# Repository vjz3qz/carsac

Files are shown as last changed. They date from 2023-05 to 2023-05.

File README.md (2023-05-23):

# CARS Access Control
Access control solution for the Charlottesville-Albemarle Rescue Squad. The CARS Access Control Software is an RFID badge scanning system for streamlined and secure access control. It offers real-time monitoring and customizable access management for enhanced security.

## License
Copyright 2021, 2022 by John Kothmann, Tom Baker, and Varun Pasupuleti

This file is part of CARSAC.

CARSAC is free software: you can redistribute it and/or modify it under the terms of the GNU General Public License as published by the Free Software Foundation, either version 3 of the License, or (at your option) any later version.

CARSAC is distributed in the hope that it will be useful, but WITHOUT ANY WARRANTY; without even the implied warranty of MERCHANTABILITY or FITNESS FOR A PARTICULAR PURPOSE. See the GNU General Public License for more details.

You should have received a copy of the GNU General Public License along with CARSAC. If not, see <https://www.gnu.org/licenses/>.

## Hardware and setup

Install a strike in the door. Use a fail-secure strike for secure facilities like a telecom closet and fail-open for doors essential for egress and rescue workers like main entrances. In the event of a power outage and depletion of the backup battery, does the door need to be locked or unlocked? Ideally, install the diode to prevent high-voltage spikes when power is disconnected but the strike coil magnetic field transiently remains.

Print a case and attach Pi 0W, Adafruit Trinket/Feather, and wiring board to the case. Solder headers to the Pi 0W and wiring board if desired for easier troubleshooting. Otherwise, solder wires between elements as indicated on the wiring board.

Connect the power supply to the wiring board per the labels on the wiring board. Use Normally Closed (NC) for fail-open and Normally Open (NO) for fail-secure strikes.

## Configuration

Install Raspbian (32-bit, headless/the lightest image possible).

Update the hostname and enable SSH with `sudo raspi-config` (general and interfacing options).

Delete the default pi user (`sudo userdel pi`)

Add desired users and their SSH keys and add them to the sudoers group (`sudo useradd -m -G sudo ansible` then `ssh-copy-id -i ~/.ssh/id_ed25519.pub ansible@A.B.C.D`)

Clone git repo into /etc/carsac (may work best with scp from host after `sudo mkdir /etc/carsac`)

Edit door-specific config information in `/etc/carsac/config.ini` (door_id)

Set up CARSAC service with `sudo mv /etc/carsac/carsac.service /etc/systemd/system/carsac.service`, `sudo systemctl daemon-reload`, `sudo systemctl enable carsac`, `sudo systemctl start carsac`

Test for functionality

Set DHCP reservation on the router and add the new machine IP to /etc/ansible/hosts on the ansible master node. Login from the master to the client via SSH and perform fingerprint verification.

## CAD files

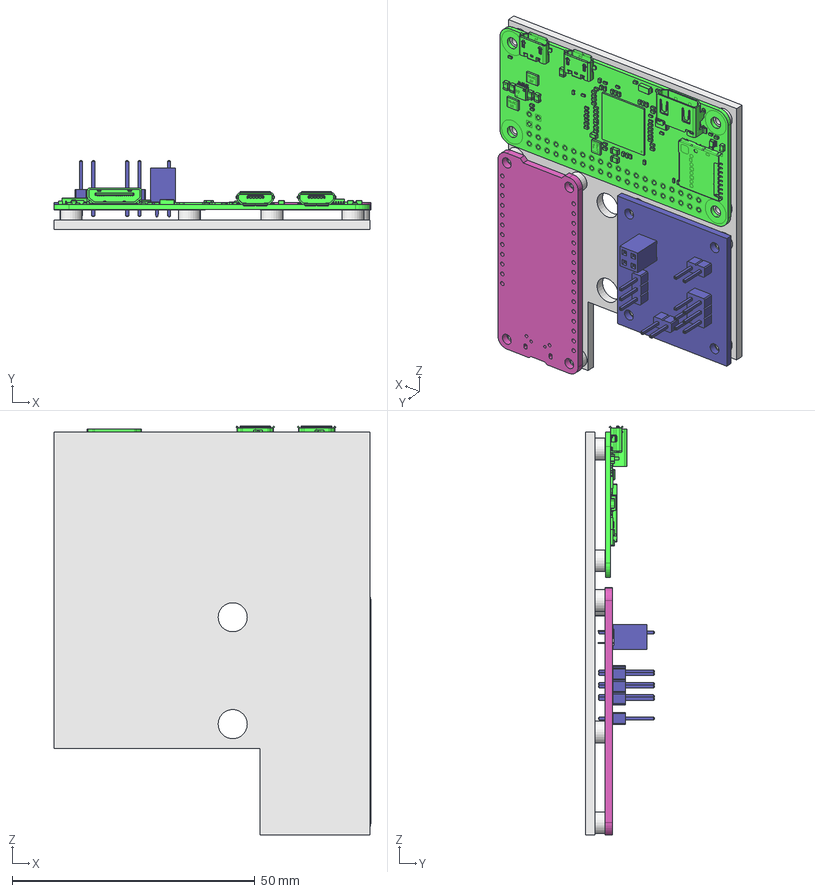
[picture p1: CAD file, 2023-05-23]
hardware/FlatCaseFeather.FCStd
65.2 x 14.2 x 84.2 mm
RapberryPiZero
ACWB
Feather
Merged

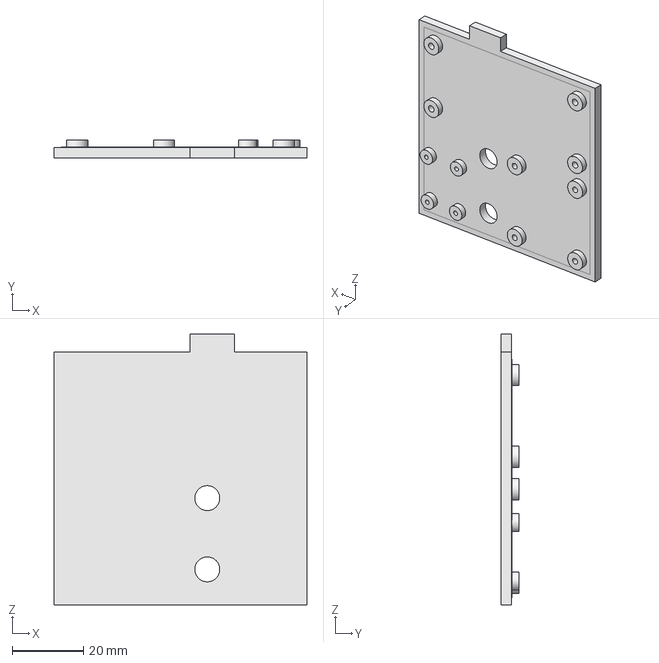
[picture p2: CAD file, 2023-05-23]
hardware/FlatCaseTrinket.FCStd
71.0 x 5.00 x 76.1 mm

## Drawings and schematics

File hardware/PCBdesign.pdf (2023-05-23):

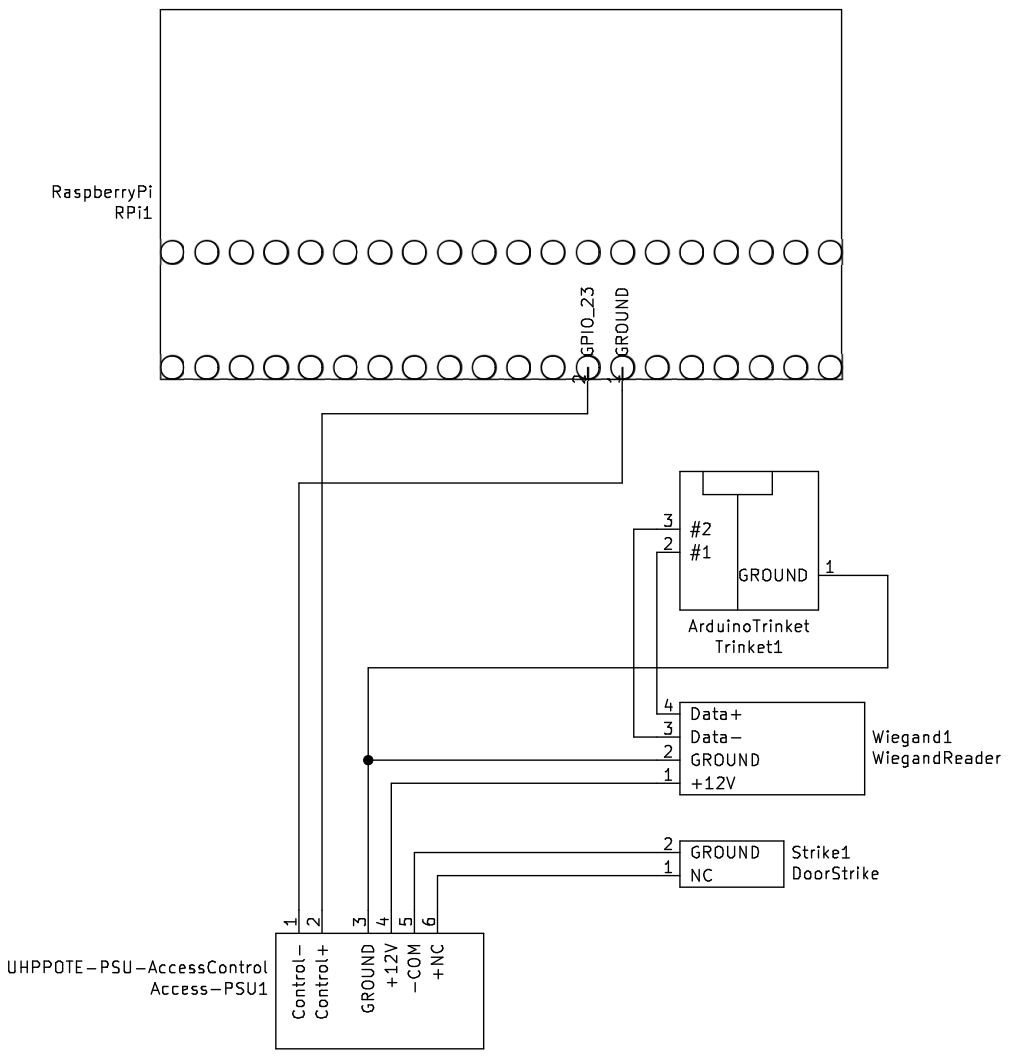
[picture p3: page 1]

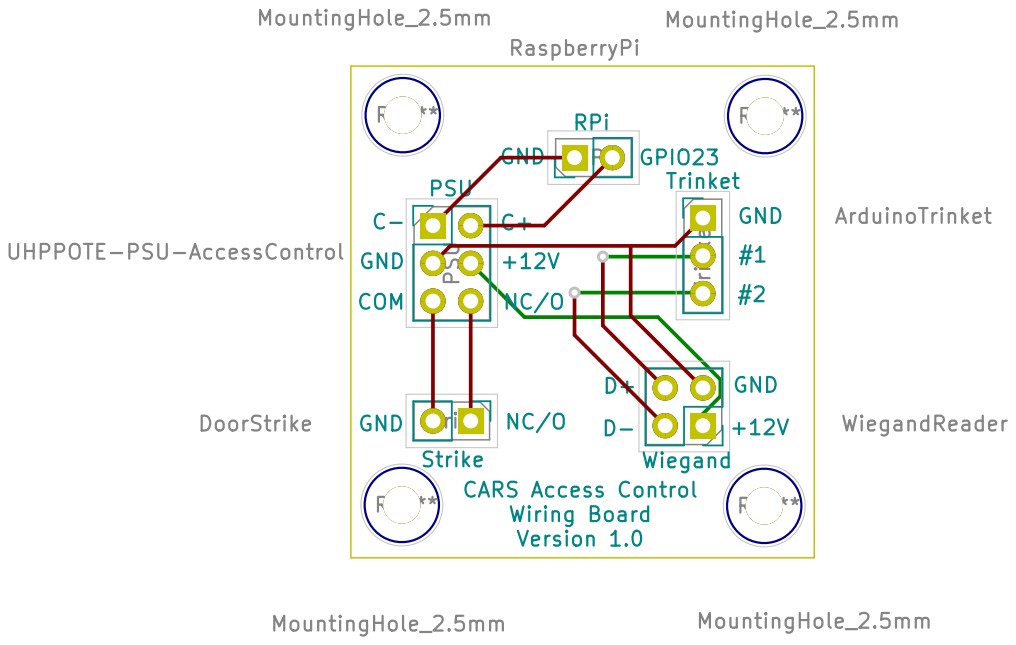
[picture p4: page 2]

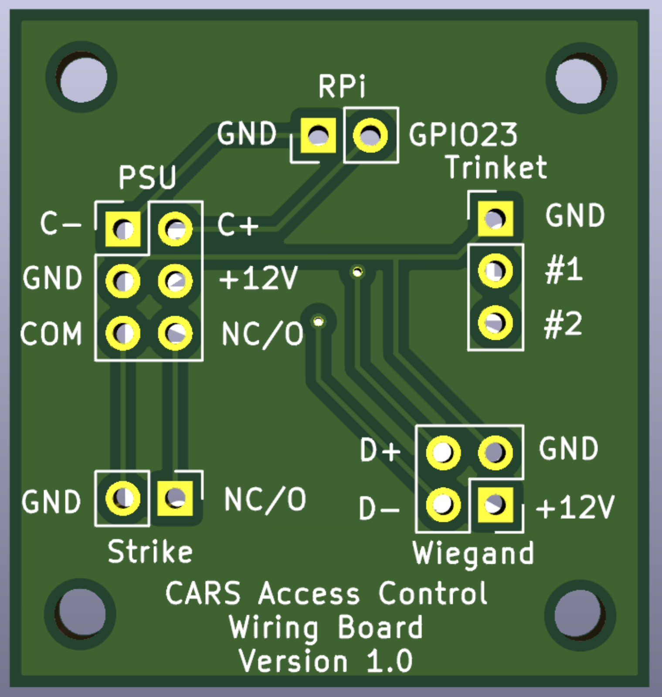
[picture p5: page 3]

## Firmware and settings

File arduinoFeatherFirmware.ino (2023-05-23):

#include <Wiegand.h>
#include "Adafruit_Keypad.h"

// These are the pins connected to the Wiegand D0 and D1 signals.
// Ensure your board supports external Interruptions on these pins
#define PIN_D0 12
#define PIN_D1 13
#define KEYPAD_PID3845
// define your pins here
// can ignore ones that don't apply
#define R1    5
#define R2    6
#define R3    10
#define R4    11
#define C1    A1
#define C2    A2
#define C3    A3
#include "keypad_config.h"
// The object that handles the wiegand protocol
Wiegand wiegand;
Adafruit_Keypad customKeypad = Adafruit_Keypad( makeKeymap(keys), rowPins, colPins, ROWS, COLS);
char PIN[10];
int semafoo = 0;
int keyPadTimeOut = 0;
// Initialize Wiegand reader
void setup() {
  Serial.begin(9600);
  customKeypad.begin();
  //Install listeners and initialize Wiegand reader
  wiegand.onReceive(receivedData, "Card readed: ");
  wiegand.onReceiveError(receivedDataError, "Error with message verification");
  wiegand.onStateChange(stateChanged, "State changed: ");
  wiegand.begin(Wiegand::LENGTH_ANY, true);

  //initialize pins as INPUT and attaches interruptions
  pinMode(PIN_D0, INPUT);
  pinMode(PIN_D1, INPUT);
  attachInterrupt(digitalPinToInterrupt(PIN_D0), pinStateChanged, CHANGE);
  attachInterrupt(digitalPinToInterrupt(PIN_D1), pinStateChanged, CHANGE);

  //Sends the initial pin state to the Wiegand library
  pinStateChanged();
}

// Every few milliseconds, check for pending messages on the wiegand reader
// This executes with interruptions disabled, since the Wiegand library is not thread-safe
void loop() {
  customKeypad.tick(); //scan keypad
  semafoo++; //increment counter (flush only runs every 10th loop)
  keyPadTimeOut++;
  while(customKeypad.available()){
    keypadEvent e = customKeypad.read();
    if(e.bit.EVENT == KEY_JUST_PRESSED) {
      keyPadTimeOut = 1;
      if((char)e.bit.KEY != '#') {
        for(int i = 0; i < 10; i++) {
          if(PIN[i] == 0x00) {
            PIN[i] = (char)e.bit.KEY;
            break;
          }
        }
       } else {
        Serial.print("PIN: ");
        Serial.println(PIN);
        for(int i = 0; i < 10; i++) {
          PIN[i] = 0x00;
        }
      }
    }
  }
  //wiegand flush (not really sure what it does but wiegand library runs it every 100ms)
  if(semafoo % 10 == 0) {
    noInterrupts();
    wiegand.flush();
    interrupts();
  } if(keyPadTimeOut % 400 == 0) {
    //Every 4 seconds w/o button press clear keypad
    for(int i = 0; i < 10; i++) {
      PIN[i] = 0x00;
    }
  }
  delay(10);
}

// When any of the pins have changed, update the state of the wiegand library
void pinStateChanged() {
  wiegand.setPin0State(digitalRead(PIN_D0));
  wiegand.setPin1State(digitalRead(PIN_D1));
}

// Notifies when a reader has been connected or disconnected.
// Instead of a message, the seconds parameter can be anything you want -- Whatever you specify on `wiegand.onStateChange()`
void stateChanged(bool plugged, const char* message) {
    Serial.print(message);
    Serial.println(plugged ? "CONNECTED" : "DISCONNECTED");
}

// Notifies when a card was read.
// Instead of a message, the seconds parameter can be anything you want -- Whatever you specify on `wiegand.onReceive()`
void receivedData(uint8_t* data, uint8_t bits, const char* message) {
    Serial.print(message);
    Serial.print(bits);
    Serial.print("bits / ");
    //Print value in HEX
    uint8_t bytes = (bits+7)/8;
    for (int i=0; i<bytes; i++) {
        Serial.print(data[i] >> 4, 16);
        Serial.print(data[i] & 0xF, 16);
    }
    Serial.println();
}

// Notifies when an invalid transmission is detected
void receivedDataError(Wiegand::DataError error, uint8_t* rawData, uint8_t rawBits, const char* message) {
    Serial.print(message);
    Serial.print(Wiegand::DataErrorStr(error));
    Serial.print(" - Raw data: ");
    Serial.print(rawBits);
    Serial.print("bits / ");

    //Print value in HEX
    uint8_t bytes = (rawBits+7)/8;
    for (int i=0; i<bytes; i++) {
        Serial.print(rawData[i] >> 4, 16);
        Serial.print(rawData[i] & 0xF, 16);
    }
    Serial.println();
}
